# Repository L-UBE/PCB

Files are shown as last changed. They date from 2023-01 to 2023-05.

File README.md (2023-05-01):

# PCB

the pcb for cuwube

v1 - initial pcb from fall quarter

v2 - adding in voltage regulator changes

v3 - with the 0 ohm resistor for the voltage regulator

v4 - removed bluetooth module, opened pins

v5 - changed parts for JLC

v6 - third iteration of pcb, for cube

v7 - third iteration of pcb, for glove

v8 - new pcb for tri-state buffers

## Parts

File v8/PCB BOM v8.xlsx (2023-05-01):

Comment | Designator | Footprint | JLCPCB Part # | Description
PINHD-1X2 | IN, OUT1, OUT2, OUT3, OUT4, OUT5, OUT6, OUT7, OUT8, POWER, POWER1 | 1X02 | C49661 (https://jlcpcb.com/partdetail/boomele_boom_Precision_elec-C49661/C49661) | PIN HEADER
PINHD-2X2 | SS_PINS | 2X02 | C92273 (https://jlcpcb.com/partdetail/ConnflyElec-DS1023_22SF11/C92273) | PIN HEADER
1935161 | J1 | PHOENIX_1935161 | C395882 (https://jlcpcb.com/partdetail/Dibo-DB301V_5_0_2P_BUS/C395882) | Conn Terminal Blocks 2 POS 5mm Solder ST Thru-Hole 16A Check availability
GRT21BC71H475KE13L | C1, C2, C39 | CAPC2012X145N | C520074 (https://jlcpcb.com/partdetail/Yageo-CC0805KKX7R6BB475/C520074) | GRT21BC71H475KE13_ (0805, X7S:EIA, 4.7uF, DC50V)
SN74LS125ADR | 3STATEBUFFER | SOIC127P600X175-14N | C7734 (https://jlcpcb.com/partdetail/TexasInstruments-SN74LS125ADR/C7734) | Tri-state buffer

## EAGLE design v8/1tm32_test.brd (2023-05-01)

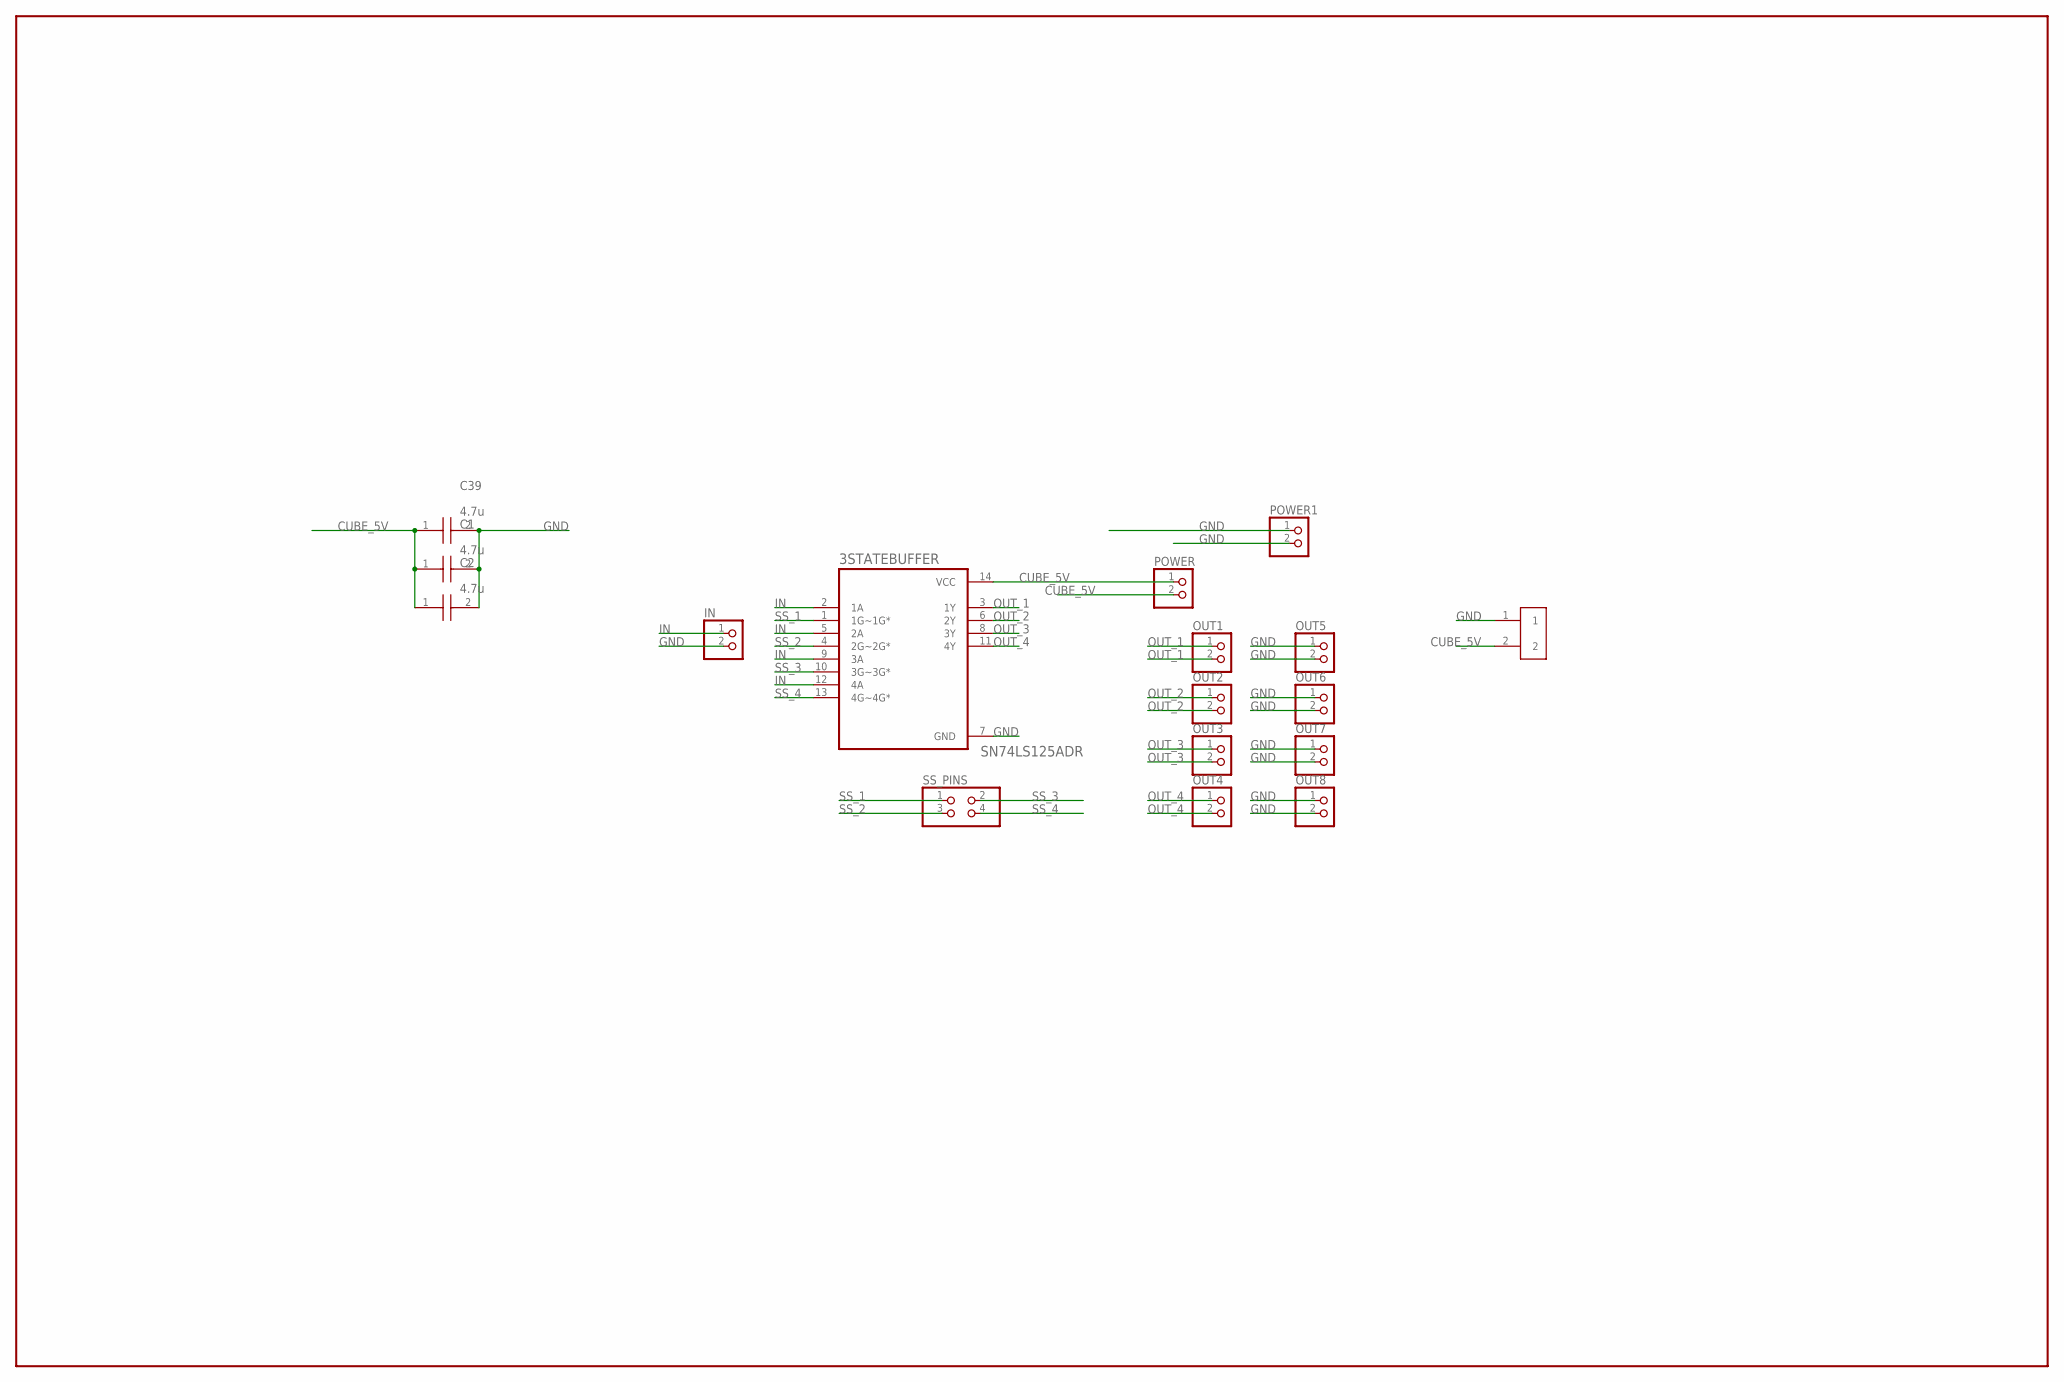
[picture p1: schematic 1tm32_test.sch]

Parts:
3STATEBUFFER: SN74LS125ADR; SOIC127P600X175-14N
C1, C2, C39: 4.7u; CAPC2012X145N
IN: PINHD-1X2; 1X02
J1: 1935161; PHOENIX_1935161
OUT1, OUT2, OUT3, OUT4, OUT5, OUT6, OUT7, OUT8: PINHD-1X2; 1X02
POWER, POWER1: PINHD-1X2; 1X02
SS_PINS: PINHD-2X2; 2X02

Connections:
CUBE_5V: 3STATEBUFFER.14 (VCC), C1.1, C2.1, C39.1, J1.2, POWER.1, POWER.2
GND: 3STATEBUFFER.7 (GND), C1.2, C2.2, C39.2, IN.2, J1.1, OUT5.1, OUT5.2, OUT6.1, OUT6.2, OUT7.1, OUT7.2, OUT8.1, OUT8.2, POWER1.1, POWER1.2
IN: 3STATEBUFFER.2 (1A), 3STATEBUFFER.5 (2A), 3STATEBUFFER.9 (3A), 3STATEBUFFER.12 (4A), IN.1
OUT_1: 3STATEBUFFER.3 (1Y), OUT1.1, OUT1.2
OUT_2: 3STATEBUFFER.6 (2Y), OUT2.1, OUT2.2
OUT_3: 3STATEBUFFER.8 (3Y), OUT3.1, OUT3.2
OUT_4: 3STATEBUFFER.11 (4Y), OUT4.1, OUT4.2
SS_1: 3STATEBUFFER.1 (1G~1G*), SS_PINS.1
SS_2: 3STATEBUFFER.4 (2G~2G*), SS_PINS.3
SS_3: 3STATEBUFFER.10 (3G~3G*), SS_PINS.2
SS_4: 3STATEBUFFER.13 (4G~4G*), SS_PINS.4

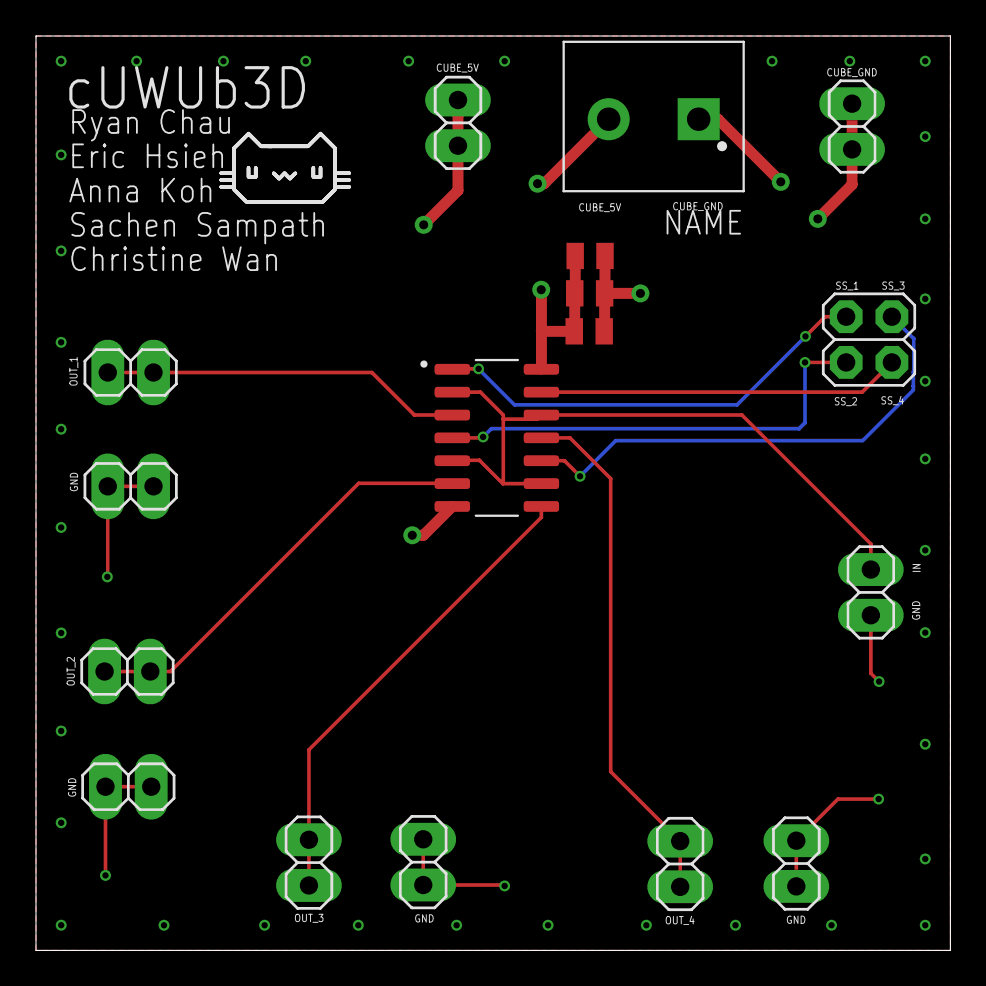
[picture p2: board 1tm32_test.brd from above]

Board: 4 copper layers, 50.8 x 50.8 mm, 17 parts (0 on the bottom side), 11 nets.

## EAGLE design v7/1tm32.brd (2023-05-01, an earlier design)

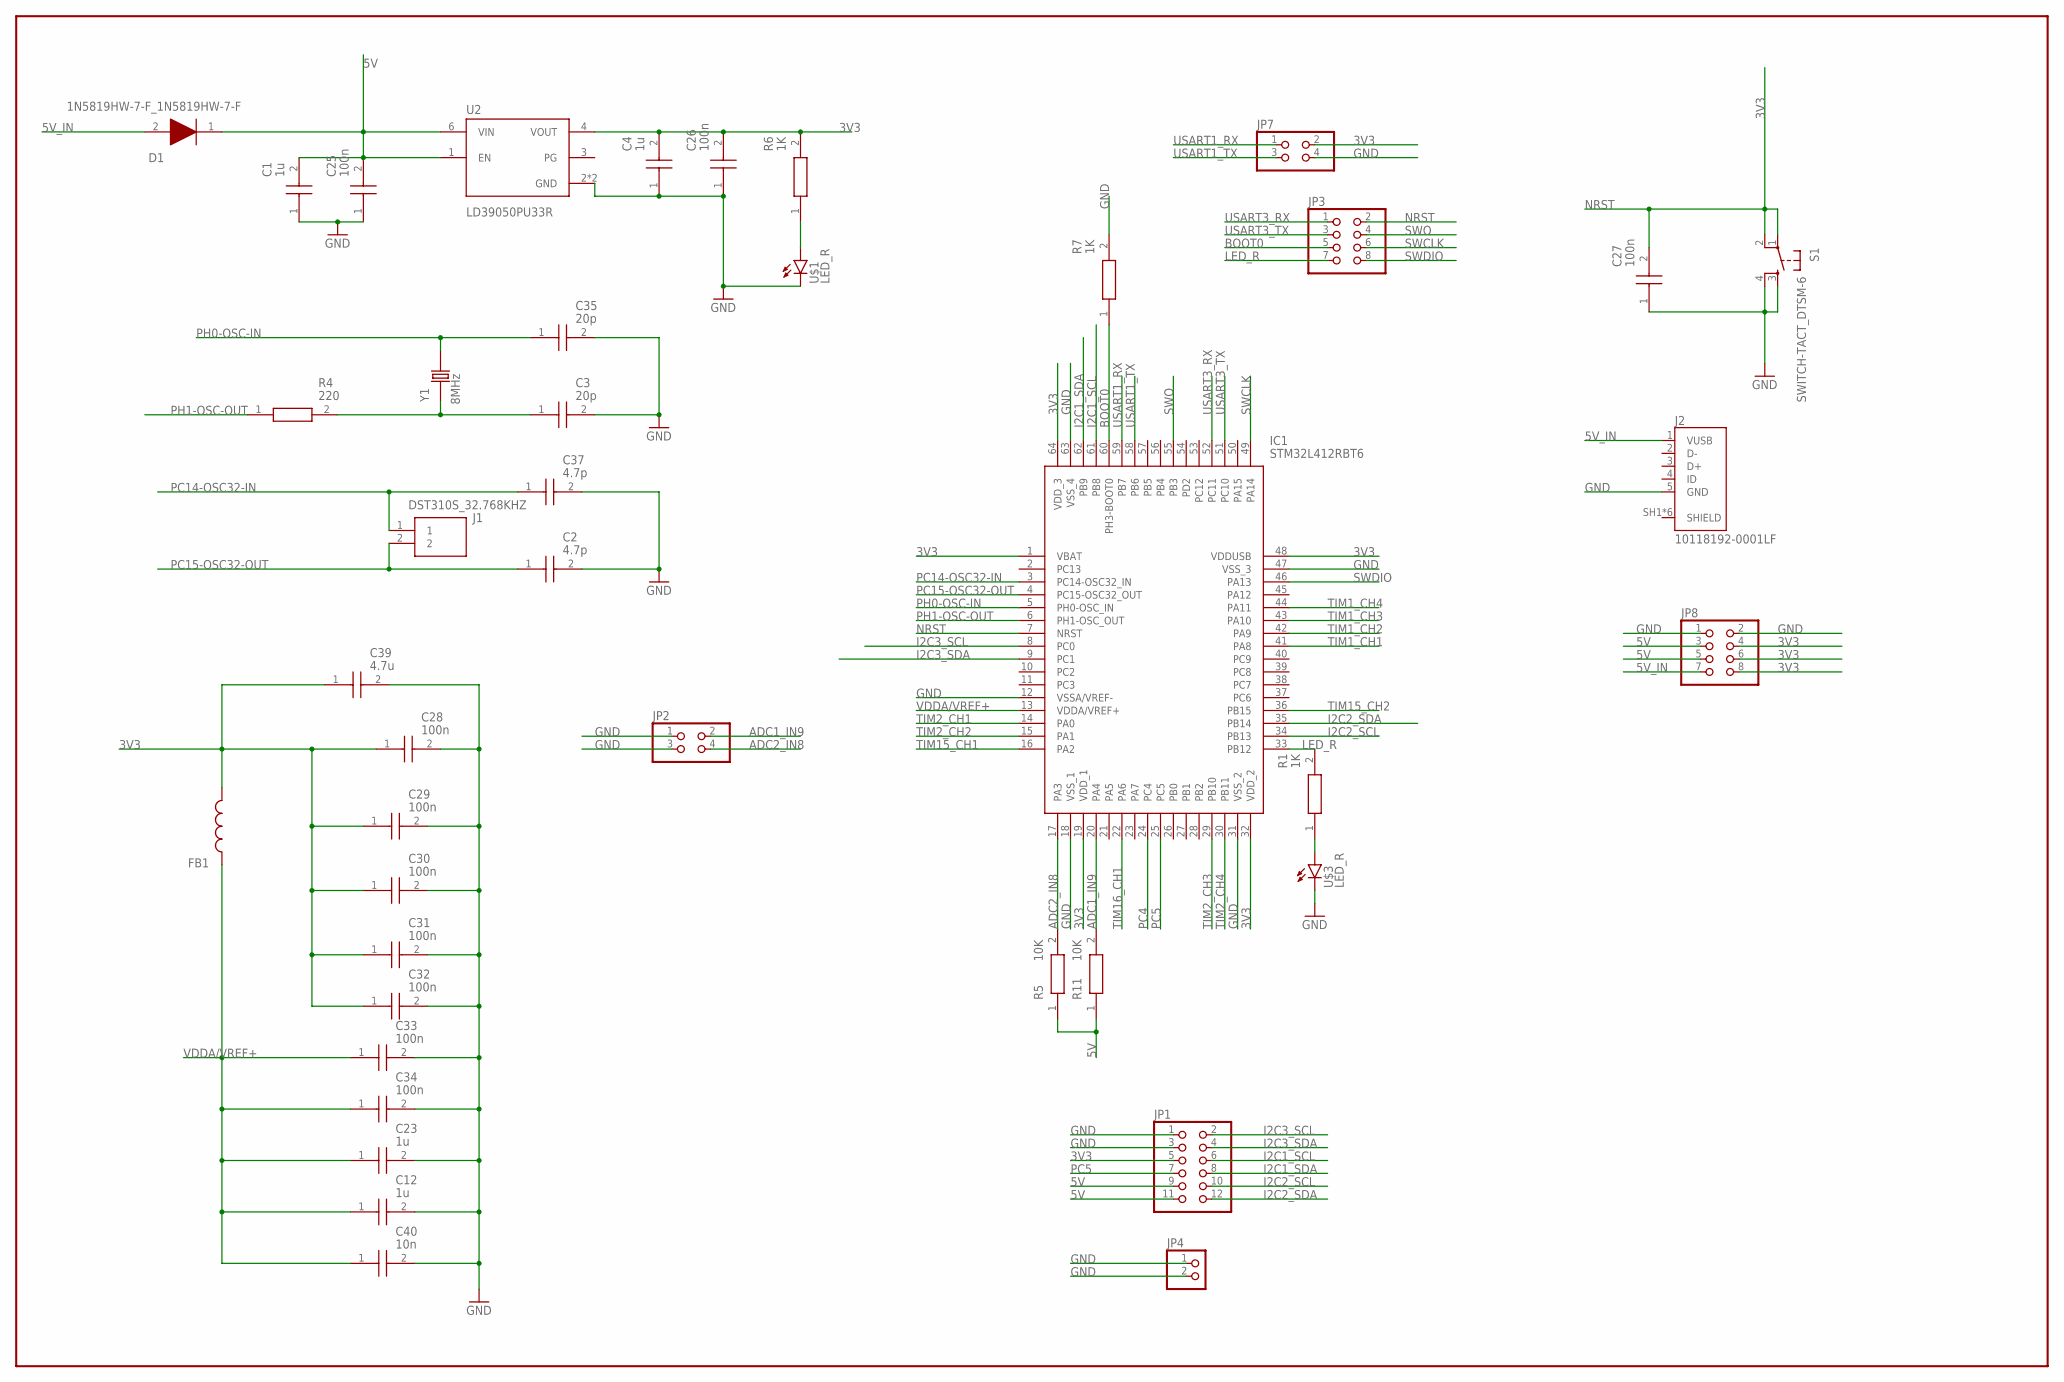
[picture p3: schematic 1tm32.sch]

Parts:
C1, C4, C12, C23: 1u; CAPC2012X95N
C2, C37: 4.7p; CAPC2012X100N
C3, C35: 20p; CAPC1005X55N
C25, C26, C27, C28, C29, C30, C31, C32, C33, C34: 100n; CAPC3216X180N
C39: 4.7u; CAPC2012X145N
C40: 10n; CAPC3216X180N
D1: 1N5819HW-7-F_1N5819HW-7-F; 1N5819HW-7-F_SOD3716X145N
FB1: BK1608HS601-T; BEADC1608X95N
IC1: STM32L412RBT6; QFP50P1200X1200X160-64N
J1: DST310S_32.768KHZ; DST310S_32.768KHZ_DST310S32768KHZ
J2: 10118192-0001LF; AMPHENOL_10118192-0001LF
JP1: PINHD-2X6; 2X06
JP2, JP7: PINHD-2X2; 2X02
JP3, JP8: PINHD-2X4; 2X04
JP4: PINHD-1X2; 1X02
R1, R6, R7: 1K; RESC2012X60N
R4: 220; RESC2012X60N
R5, R11: 10K; RESC2012X60N
S1: SWITCH-TACT_DTSM-6
U2: LD39050PU33R; SON95P300X300X100-7N
U$1, U$3: LED_R; LED_SML-P11UTT86R
Y1: 8MHz; XTAL_ABLS-8.000MHZ-B2-T

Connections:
3V3: C4.2, C26.2, C28.1, C29.1, C30.1, C31.1, C32.1, C39.1, FB1.2, IC1.1 (VBAT), IC1.19 (VDD_1), IC1.32 (VDD_2), IC1.48 (VDDUSB), IC1.64 (VDD_3), JP1.5, JP7.2, JP8.4, JP8.6, JP8.8, R6.2, U2.4 (VOUT)
5V: C1.2, C25.2, D1.1 (K), JP1.9, JP1.11, JP8.3, JP8.5, R5.1, R11.1, U2.1 (EN), U2.6 (VIN)
5V_IN: D1.2 (A), J2.1 (VUSB), JP8.7
ADC1_IN9: IC1.20 (PA4), JP2.2, R11.2
ADC2_IN8: IC1.17 (PA3), JP2.4, R5.2
BOOT0: IC1.60 (PH3-BOOT0), JP3.5, R7.1
GND: C1.1, C2.2, C3.2, C4.1, C12.2, C23.2, C25.1, C26.1, C27.1, C28.2, C29.2, C30.2, C31.2, C32.2, C33.2, C34.2, C35.2, C37.2, C39.2, C40.2, IC1.12 (VSSA/VREF-), IC1.18 (VSS_1), IC1.31 (VSS_2), IC1.47 (VSS_3), IC1.63 (VSS_4), J2.5 (GND), JP1.1, JP1.3, JP2.1, JP2.3, JP4.1, JP4.2, JP7.4, JP8.1, JP8.2, R7.2, S1.3, S1.4, U2.2 (GND), U2.7 (GND), U$1.C, U$3.C
I2C1_SCL: IC1.61 (PB8), JP1.6
I2C1_SDA: IC1.62 (PB9), JP1.8
I2C2_SCL: IC1.34 (PB13), JP1.10
I2C2_SDA: IC1.35 (PB14), JP1.12
I2C3_SCL: IC1.8 (PC0), JP1.2
I2C3_SDA: IC1.9 (PC1), JP1.4
LED_R: IC1.33 (PB12), JP3.7, R1.2
unnamed: R1.1, U$3.A
unnamed: C3.1, R4.2, Y1.1
unnamed: R6.1, U$1.A
NRST: C27.2, IC1.7 (NRST), JP3.2, S1.1, S1.2
PC4: IC1.24 (PC4)
PC5: IC1.25 (PC5), JP1.7
PC14-OSC32-IN: C37.1, IC1.3 (PC14-OSC32_IN), J1.1
PC15-OSC32-OUT: C2.1, IC1.4 (PC15-OSC32_OUT), J1.2
PH0-OSC-IN: C35.1, IC1.5 (PH0-OSC_IN), Y1.2
PH1-OSC-OUT: IC1.6 (PH1-OSC_OUT), R4.1
SWCLK: IC1.49 (PA14), JP3.6
SWDIO: IC1.46 (PA13), JP3.8
SWO: IC1.55 (PB3), JP3.4
TIM1_CH1: IC1.41 (PA8)
TIM1_CH2: IC1.42 (PA9)
TIM1_CH3: IC1.43 (PA10)
TIM1_CH4: IC1.44 (PA11)
TIM2_CH1: IC1.14 (PA0)
TIM2_CH2: IC1.15 (PA1)
TIM2_CH3: IC1.29 (PB10)
TIM2_CH4: IC1.30 (PB11)
TIM15_CH1: IC1.16 (PA2)
TIM15_CH2: IC1.36 (PB15)
TIM16_CH1: IC1.22 (PA6)
USART1_RX: IC1.59 (PB7), JP7.1
USART1_TX: IC1.58 (PB6), JP7.3
USART3_RX: IC1.52 (PC11), JP3.1
USART3_TX: IC1.51 (PC10), JP3.3
VDDA/VREF+: C12.1, C23.1, C33.1, C34.1, C40.1, FB1.1, IC1.13 (VDDA/VREF+)

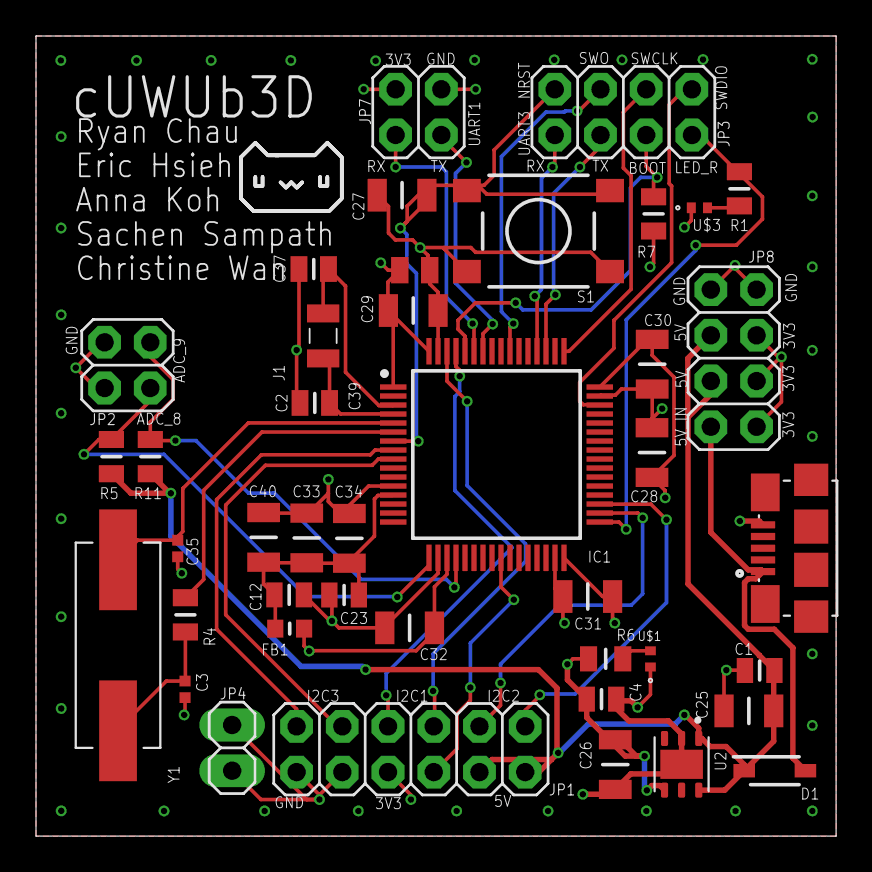
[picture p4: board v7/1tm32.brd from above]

Board: 4 copper layers, 44.5 x 44.5 mm, 42 parts (0 on the bottom side), 31 nets.

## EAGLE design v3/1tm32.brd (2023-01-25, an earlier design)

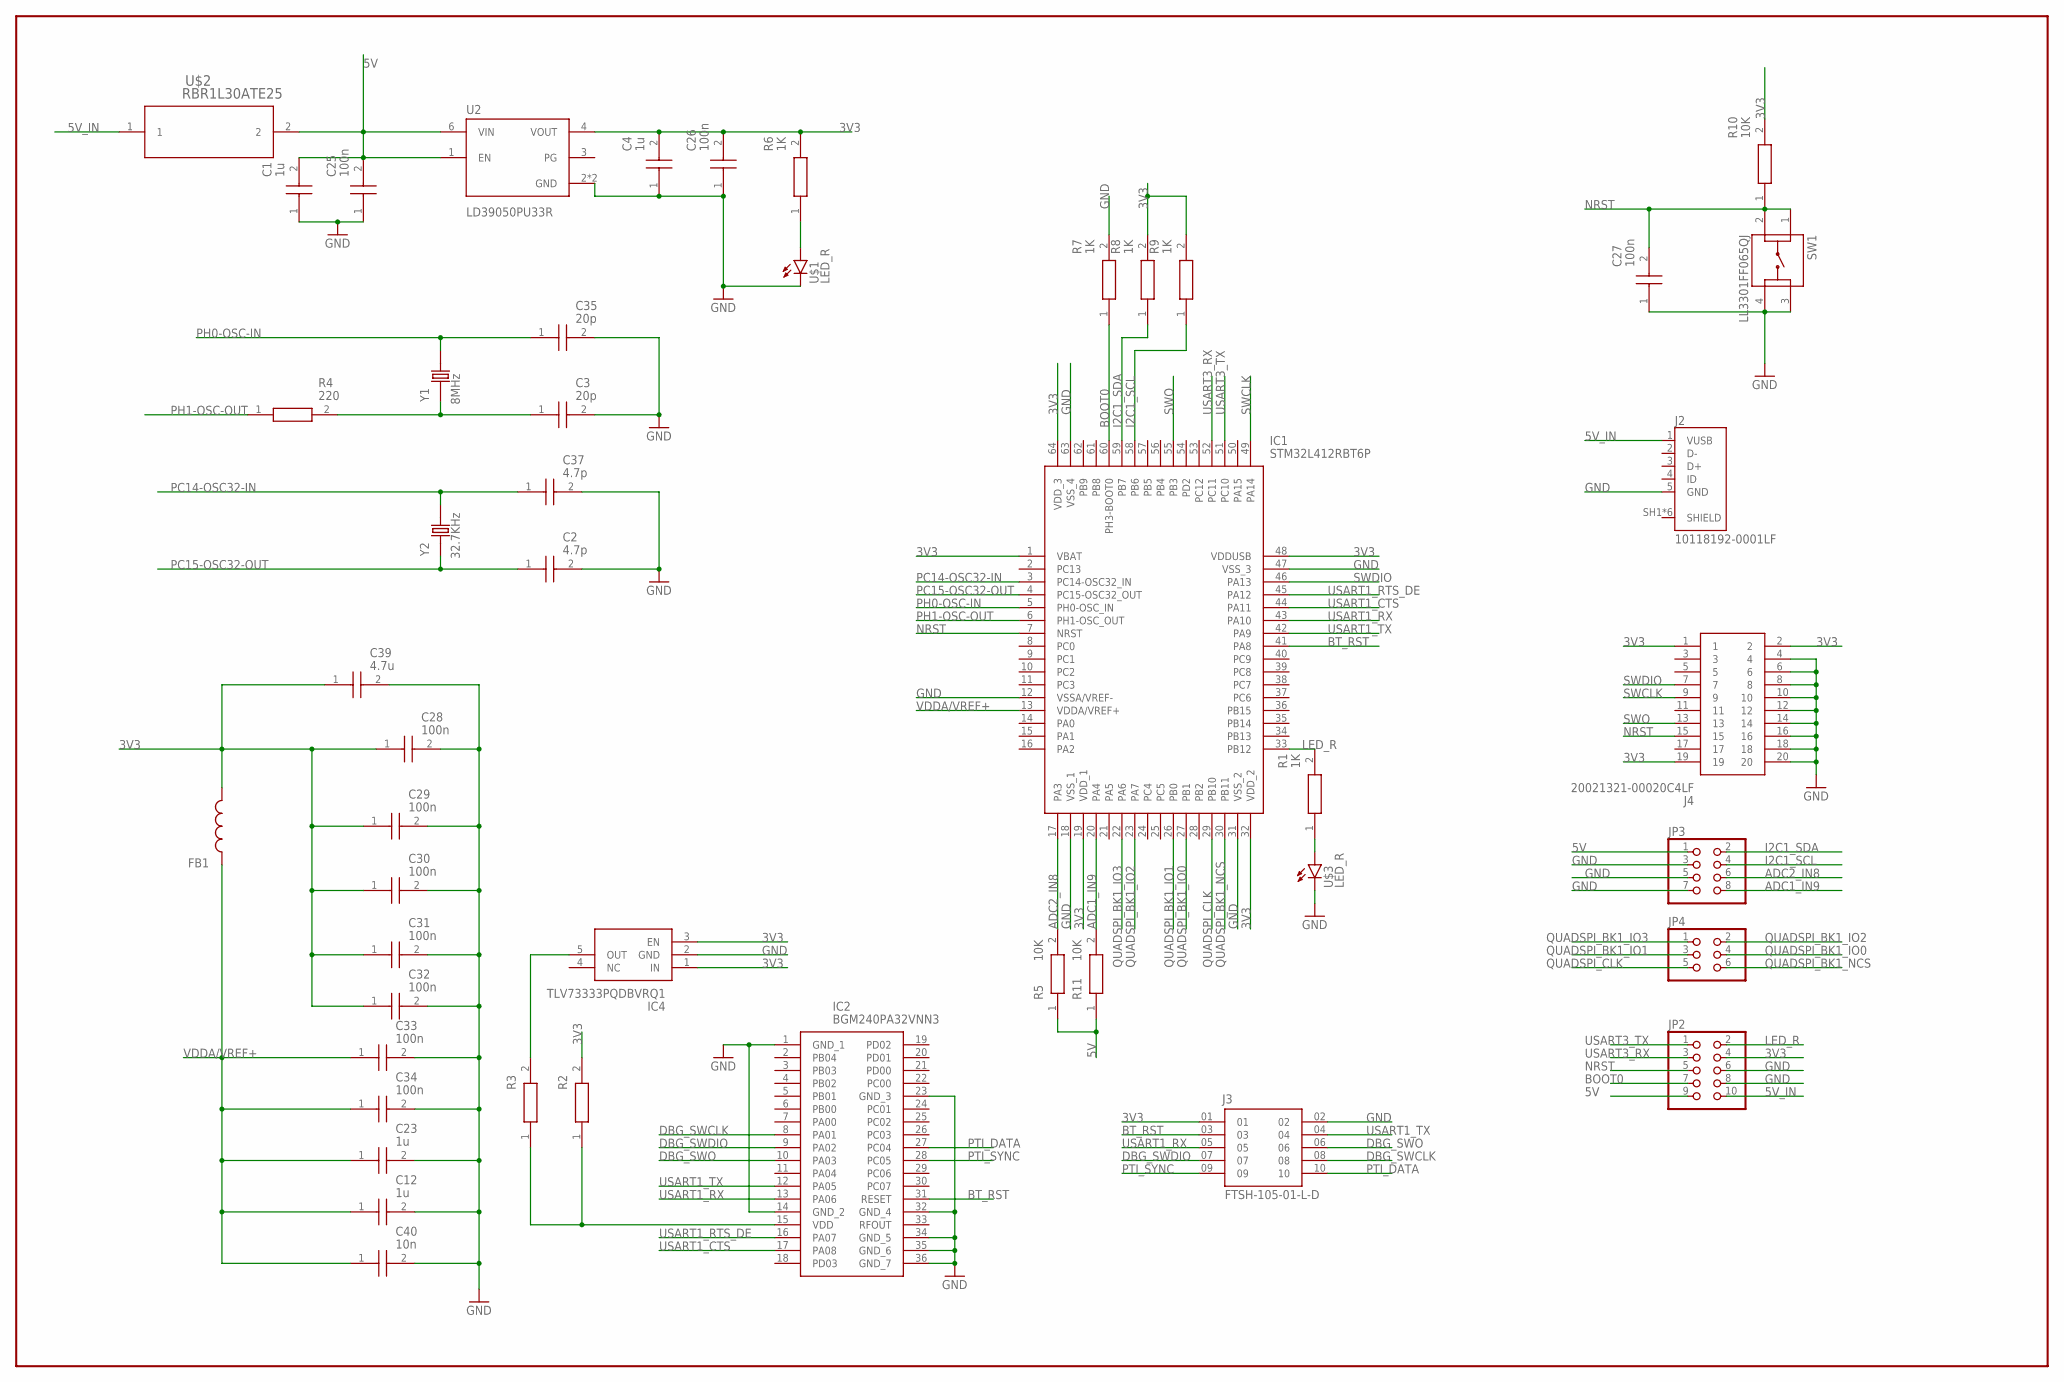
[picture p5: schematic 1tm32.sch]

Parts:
C1, C4, C12, C23: 1u; CAPC2012X95N
C2, C37: 4.7p; CAPC2012X100N
C3, C35: 20p; CAPC2012X100N
C25, C26, C27, C28, C29, C30, C31, C32, C33, C34: 100n; CAPC3216X180N
C39: 4.7u; CAPC2012X145N
C40: 10n; CAPC3216X180N
FB1: BK1608HS601-T; BEADC1608X95N
IC1: STM32L412RBT6P; QFP50P1200X1200X160-64N
IC2: BGM240PA32VNN3
IC4: TLV73333PQDBVRQ1; SOT95P280X145-5N
J2: 10118192-0001LF; AMPHENOL_10118192-0001LF
J3: FTSH-105-01-L-D; SAMTEC_FTSH-105-01-L-D
J4: 20021321-00020C4LF; 2002132100020C4LF
JP2: PINHD-2X5; 2X05
JP3: PINHD-2X4; 2X04
JP4: PINHD-2X3; 2X03
R1, R6, R7, R8, R9: 1K; RESC2012X60N
R2, R3: PMR01ZZPJ000; RESC1005X35N
R4: 220; RESC2012X60N
R5, R10, R11: 10K; RESC2012X60N
SW1: LL3301FF065QJ
U2: LD39050PU33R; SON95P300X300X100-7N
U$1, U$3: LED_R; LED_SML-P11UTT86R
U$2: RBR1L30ATE25; DIO_RBR1L30_ROM
Y1: 8MHz; XTAL_ABLS-8.000MHZ-B2-T
Y2: 32.7KHz; XTAL_ECS-.327-12.5-12QS-TR

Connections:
3V3: C4.2, C26.2, C28.1, C29.1, C30.1, C31.1, C32.1, C39.1, FB1.2, IC1.1 (VBAT), IC1.19 (VDD_1), IC1.32 (VDD_2), IC1.48 (VDDUSB), IC1.64 (VDD_3), IC4.1 (IN), IC4.3 (EN), J3.01, J4.1, J4.2, J4.19, JP2.4, R2.2, R6.2, R8.2, R9.2, R10.2, U2.4 (VOUT)
5V: C1.2, C25.2, JP2.9, JP3.1, R5.1, R11.1, U2.1 (EN), U2.6 (VIN), U$2.2
5V_IN: J2.1 (VUSB), JP2.10, U$2.1
ADC1_IN9: IC1.20 (PA4), JP3.8, R11.2
ADC2_IN8: IC1.17 (PA3), JP3.6, R5.2
BOOT0: IC1.60 (PH3-BOOT0), JP2.7, R7.1
BT_RST: IC1.41 (PA8), IC2.31 (RESET), J3.03
DBG_SWCLK: IC2.8 (PA01), J3.08
DBG_SWDIO: IC2.9 (PA02), J3.07
DBG_SWO: IC2.10 (PA03), J3.06
GND: C1.1, C2.2, C3.2, C4.1, C12.2, C23.2, C25.1, C26.1, C27.1, C28.2, C29.2, C30.2, C31.2, C32.2, C33.2, C34.2, C35.2, C37.2, C39.2, C40.2, IC1.12 (VSSA/VREF-), IC1.18 (VSS_1), IC1.31 (VSS_2), IC1.47 (VSS_3), IC1.63 (VSS_4), IC2.1 (GND_1), IC2.14 (GND_2), IC2.23 (GND_3), IC2.32 (GND_4), IC2.34 (GND_5), IC2.35 (GND_6), IC2.36 (GND_7), IC4.2 (GND), J2.5 (GND), J3.02, J4.4, J4.6, J4.8, J4.10, J4.12, J4.14, J4.16, J4.18, J4.20, JP2.6, JP2.8, JP3.3, JP3.5, JP3.7, R7.2, SW1.3, SW1.4, U2.2 (GND), U2.7 (GND), U$1.C, U$3.C
I2C1_SCL: IC1.58 (PB6), JP3.4, R9.1
I2C1_SDA: IC1.59 (PB7), JP3.2, R8.1
LED_R: IC1.33 (PB12), JP2.2, R1.2
unnamed: IC4.5 (OUT), R3.2
unnamed: R1.1, U$3.A
unnamed: C3.1, R4.2, Y1.1
unnamed: IC2.15 (VDD), R2.1, R3.1
unnamed: R6.1, U$1.A
NRST: C27.2, IC1.7 (NRST), J4.15, JP2.5, R10.1, SW1.1, SW1.2
PC14-OSC32-IN: C37.1, IC1.3 (PC14-OSC32_IN), Y2.2
PC15-OSC32-OUT: C2.1, IC1.4 (PC15-OSC32_OUT), Y2.1
PH0-OSC-IN: C35.1, IC1.5 (PH0-OSC_IN), Y1.2
PH1-OSC-OUT: IC1.6 (PH1-OSC_OUT), R4.1
PTI_DATA: IC2.27 (PC04), J3.10
PTI_SYNC: IC2.28 (PC05), J3.09
QUADSPI_BK1_IO0: IC1.27 (PB1), JP4.4
QUADSPI_BK1_IO1: IC1.26 (PB0), JP4.3
QUADSPI_BK1_IO2: IC1.23 (PA7), JP4.2
QUADSPI_BK1_IO3: IC1.22 (PA6), JP4.1
QUADSPI_BK1_NCS: IC1.30 (PB11), JP4.6
QUADSPI_CLK: IC1.29 (PB10), JP4.5
SWCLK: IC1.49 (PA14), J4.9
SWDIO: IC1.46 (PA13), J4.7
SWO: IC1.55 (PB3), J4.13
USART1_CTS: IC1.44 (PA11), IC2.17 (PA08)
USART1_RTS_DE: IC1.45 (PA12), IC2.16 (PA07)
USART1_RX: IC1.43 (PA10), IC2.13 (PA06), J3.05
USART1_TX: IC1.42 (PA9), IC2.12 (PA05), J3.04
USART3_RX: IC1.52 (PC11), JP2.3
USART3_TX: IC1.51 (PC10), JP2.1
VDDA/VREF+: C12.1, C23.1, C33.1, C34.1, C40.1, FB1.1, IC1.13 (VDDA/VREF+)

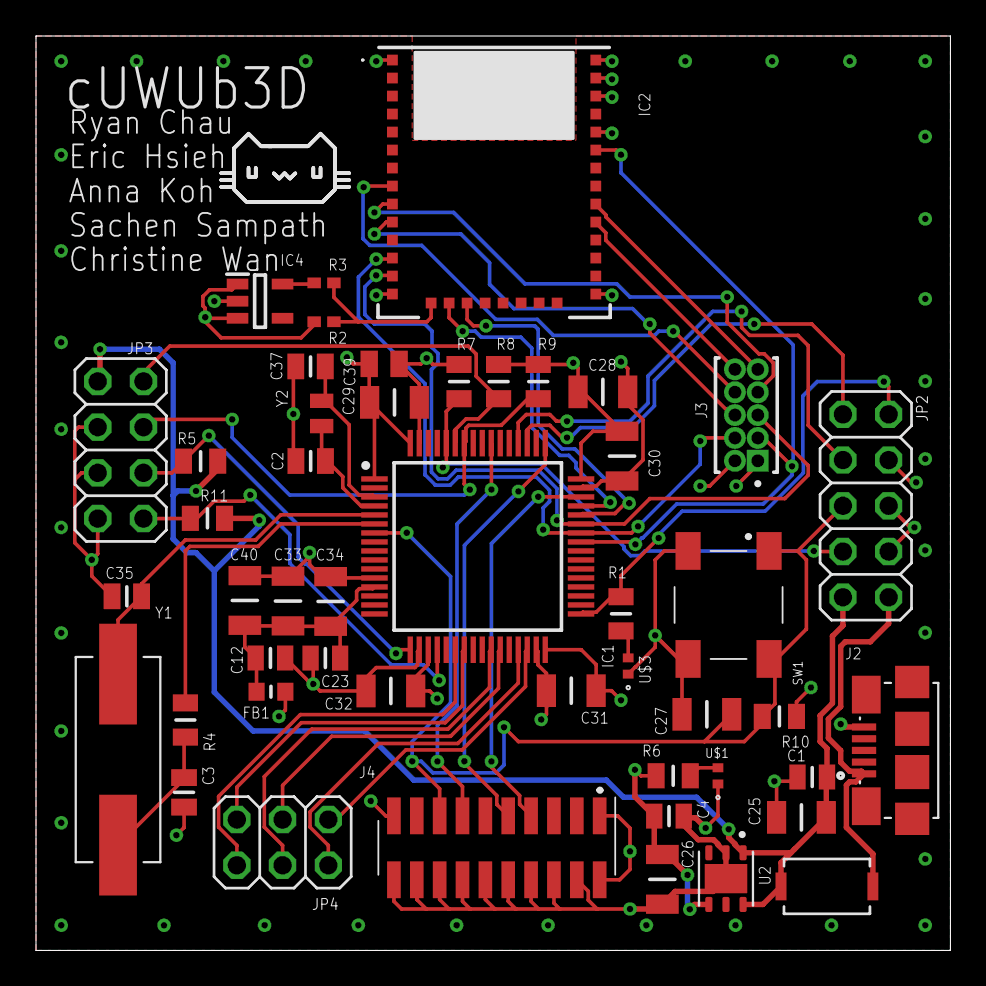
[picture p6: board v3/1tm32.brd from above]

Board: 4 copper layers, 50.8 x 50.8 mm, 48 parts (0 on the bottom side), 42 nets.

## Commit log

2022-12-02 PCB files upload
    [1tm32.brd, 1tm32.sch]
2022-12-05 layout completed
    [1tm32.brd, 1tm32.sch]
2022-12-07 add gnd vias and change adc resistors
    [1tm32.brd, 1tm32.sch]
2022-12-07 add subfolder
    [1tm32.brd]
2022-12-07 add to subfolder
    [1tm32.sch]
2023-01-11 updated the Schottky diode to RBR1L30ATE25
    datasheet: https://www.mouser.com/datasheet/2/348/ROHM_S_A0008995718_1-2562906.pdf
    [1tm32.brd, 1tm32.sch]
2023-01-13 changed errors
    [1tm32.brd, 1tm32.sch]
2023-01-18 cloning before adding in voltage regulator
2023-01-18 cloning before voltage regulator
2023-01-18 add voltage regulator version
    [1tm32.brd, 1tm32.sch]
2023-01-18 move file into directory
    [1tm32.brd]
2023-01-18 move file to directory
    [1tm32.sch]
2023-01-19 changed voltage regulator
    previous one caused clearance issues with the wires
    [1tm32.brd, 1tm32.sch]
2023-01-25 added 0 ohm resistor
    [1tm32.brd, 1tm32.sch]
2023-03-10 added labels for header pins
    [1tm32.brd]
2023-03-11 modified i2c headers
    removed resistors
    changed 3v3 pins to gpio pins
    [1tm32.brd, 1tm32.sch]
2023-03-11 moved some wires around
    [1tm32.brd]
2023-03-16 moved wire around to space for pwm wave
    [1tm32.brd, 1tm32.sch]
2023-03-16 moved a via
    [1tm32.brd]
2023-03-16 moved wires around to meet design rules for JLC
    [1tm32.brd]
2023-03-17 changed parts for jlc
    [1tm32.brd, 1tm32.sch]
2023-03-17 removed resistor for switch
    [1tm32.brd, 1tm32.sch]
2023-03-17 moved wires around
    [1tm32.brd]
2023-04-27 pcb version for cube
    [1tm32.brd, 1tm32.sch]
2023-04-27 added labels for pins
    [1tm32.brd]
2023-04-28 made changes to traces
    [1tm32.brd, 1tm32.sch]
2023-05-01 buffer circuit
    [1tm32_test.brd, 1tm32_test.sch, PCB BOM v8.xlsx]

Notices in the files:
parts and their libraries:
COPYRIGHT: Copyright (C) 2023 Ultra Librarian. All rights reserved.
